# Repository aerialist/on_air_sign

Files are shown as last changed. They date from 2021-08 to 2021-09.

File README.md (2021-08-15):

# on_air_sign
An ON_AIR sign board with RGB LED matrix and a separate controller 

# make secret.py file
You would need to make secret.py file with following contents:

secrets = {
    'ssid' : 'yourssid', # home wifi access point ssid
    'password' : 'ssidpassword', # password for ssid
    'timezone' : "Asia/Tokyo", # http://worldtimeapi.org/timezones
    'aio_username': "aiouser", # Adafruit IO user name
    'aio_password': "aiokey", # Adafruit IO password
    'broker': "awsiotxxx.amazonaws.com", # AWS IoT Device data endpoint
    "client_id": "on_air_sign_featherm4", # AWS IoT Things name for testing
    "client_id_controller": "on_air_sign_controller", # AWS IoT Things name for controller
    "client_id_matrix": "on_air_sign_matrix", # AWS IoT Things name for matrix
}

# copy AWS IoT device certificates and private keys

Define AWS IoT Thing for controller and matrix. Download device certificates and private keys in aws folder.

aws/aws_cert_controller.pem.crt
aws/aws_cert_matrix.pem.crt
aws/private_controller.pem.key
aws/private_matrix.pem.key

# code to use Adafruit IO

code_controller.py
code_matrix.py

Copy them as code.py to controller and matrix.

# code to use AWS IoT

code_controller_aws.py
code_matrix_aws.py

Copy them as code.py to controller and matrix.

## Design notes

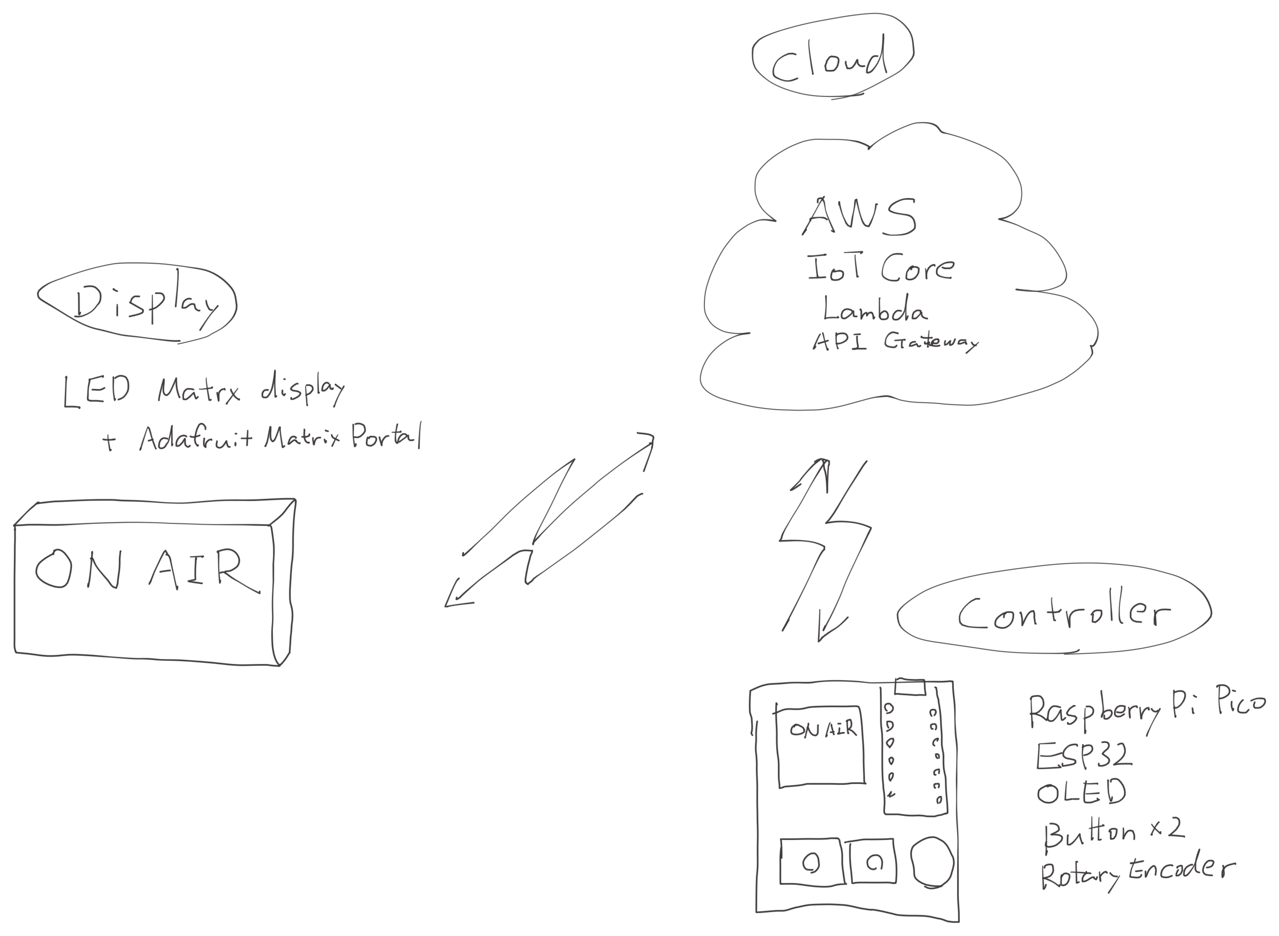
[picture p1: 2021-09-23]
images/onairsign_diagram.png

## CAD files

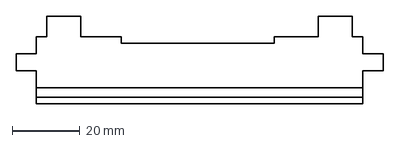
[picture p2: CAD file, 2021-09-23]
Mech/Body11.dxf
108.0 x 25.8 mm

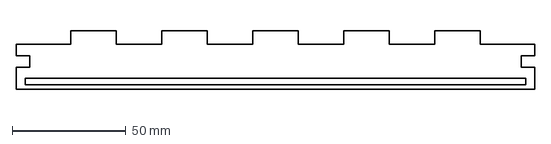
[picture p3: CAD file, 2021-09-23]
Mech/Body4.dxf
228.0 x 25.8 mm

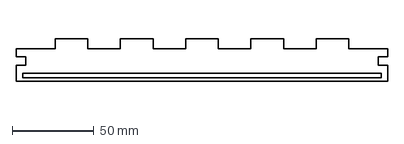
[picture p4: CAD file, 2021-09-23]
Mech/Body5.dxf
228.0 x 25.8 mm

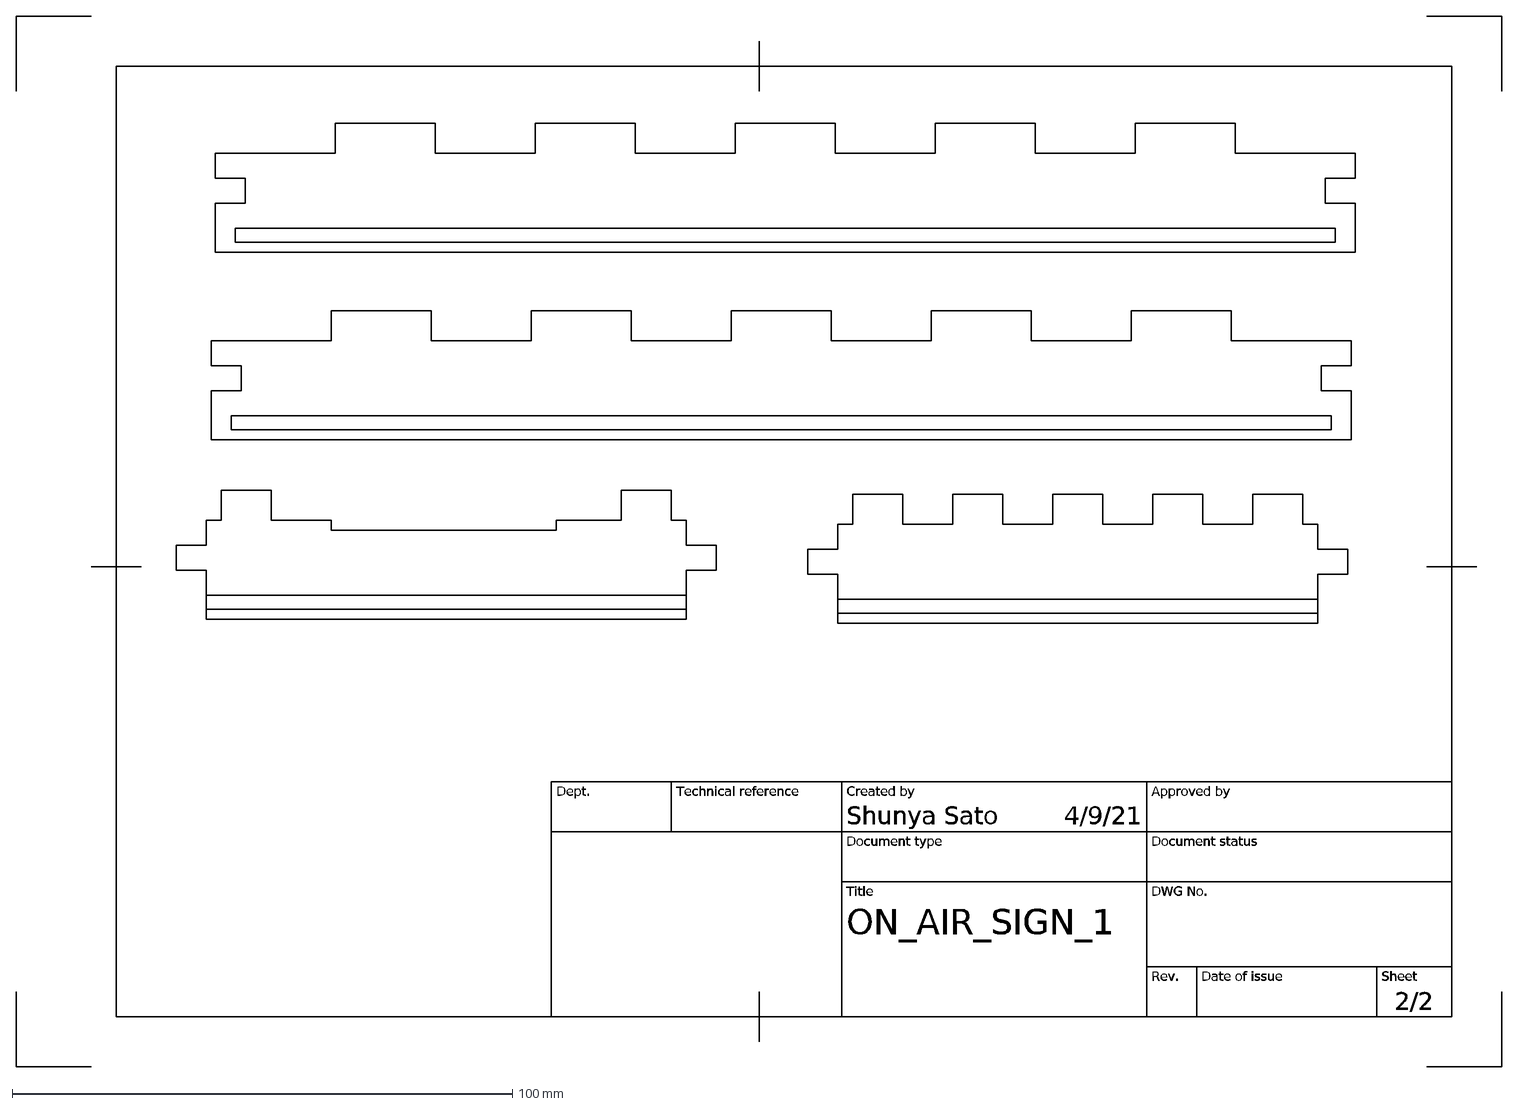
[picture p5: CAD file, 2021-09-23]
Mech/ON_AIR_SIGN_1 Drawing v3 Sheet2.dxf
4/9/21
2/2
ON_AIR_SIGN_1
Shunya Sato
Dept.
Technical reference
Created by
Approved by
Document type
Document status
Title
DWG No.
Rev.
Date of issue
Sheet

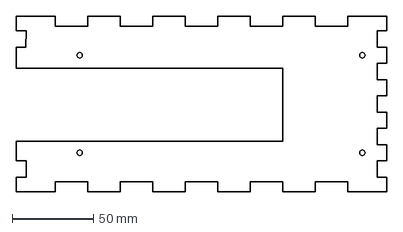
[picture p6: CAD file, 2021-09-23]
Mech/BackLid.dxf
228.0 x 108.0 mm

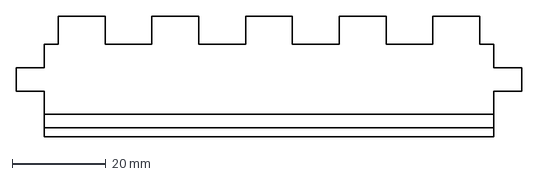
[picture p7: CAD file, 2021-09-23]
Mech/Body6.dxf
108.0 x 25.8 mm

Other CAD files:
Mech/ON_AIR_SIGN_1 Drawing v3.dwg

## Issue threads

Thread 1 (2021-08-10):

Move ESP_RESET to Pico GP16

aerialist, 2021-08-10:
ESP_RESET and ESP_GPIO0 (and ESP_CS) are used by pass through firmware.

https://learn.adafruit.com/quickstart-raspberry-pi-rp2040-with-ble-and-circuitpython/assembly

https://github.com/adafruit/Adafruit_Learning_System_Guides/blob/main/Adafruit_ESP32_Arduino_Demos/SerialESPPassthrough/serial_passthru_rp2040/serial_passthrough.c

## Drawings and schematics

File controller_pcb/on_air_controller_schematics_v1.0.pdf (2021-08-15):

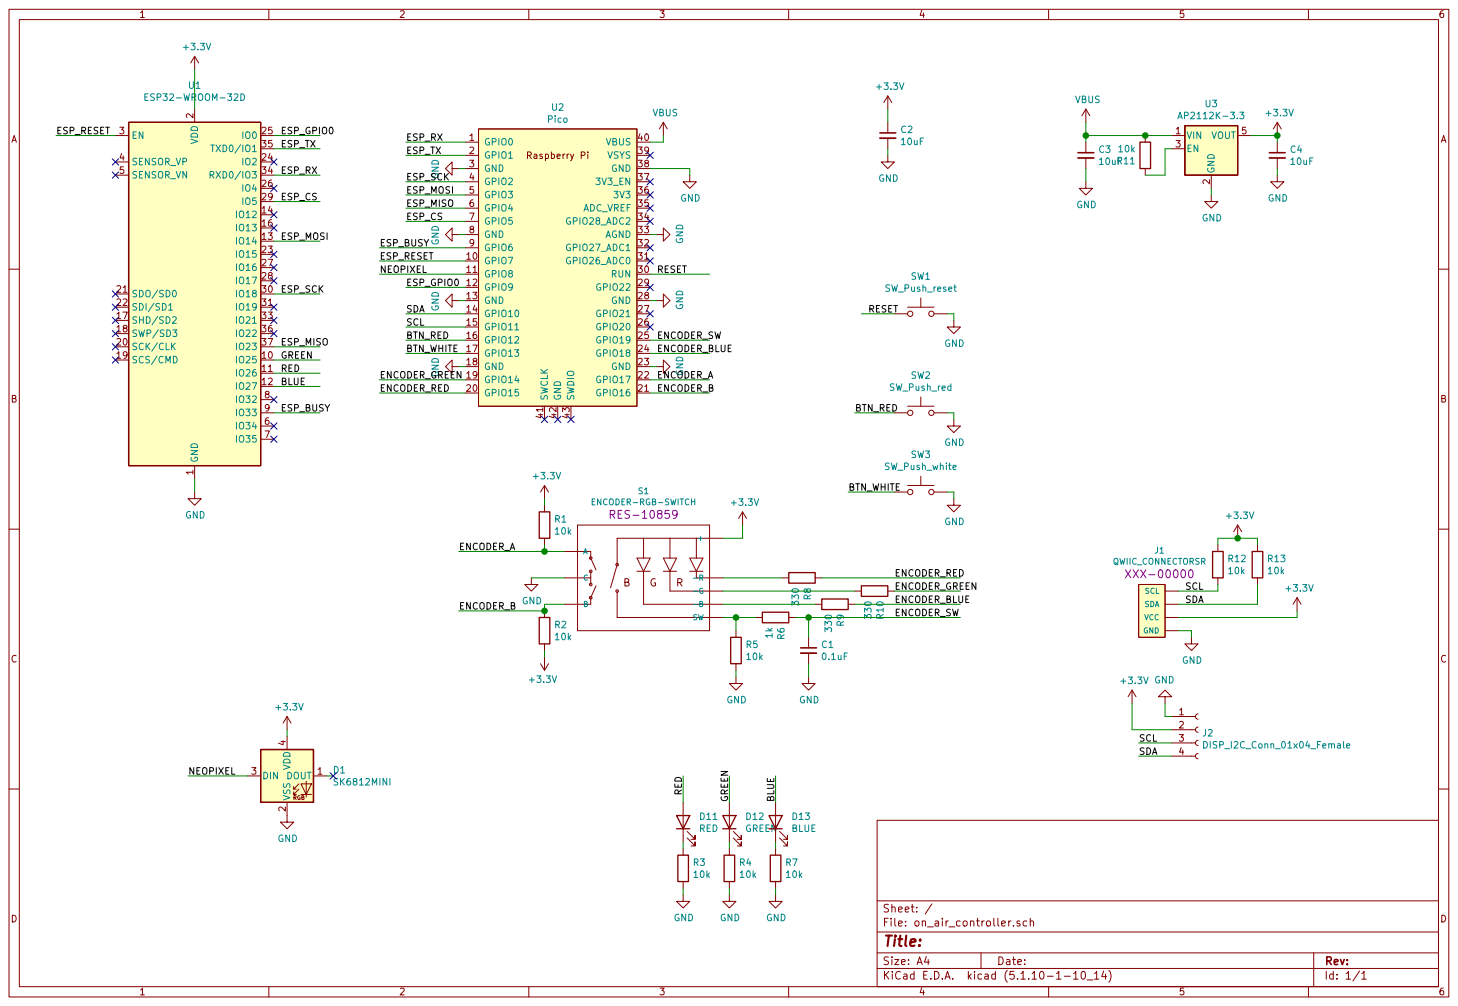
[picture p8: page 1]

2 SCK/CLK 20 SDO/SD0 21 SDI/SD1 22

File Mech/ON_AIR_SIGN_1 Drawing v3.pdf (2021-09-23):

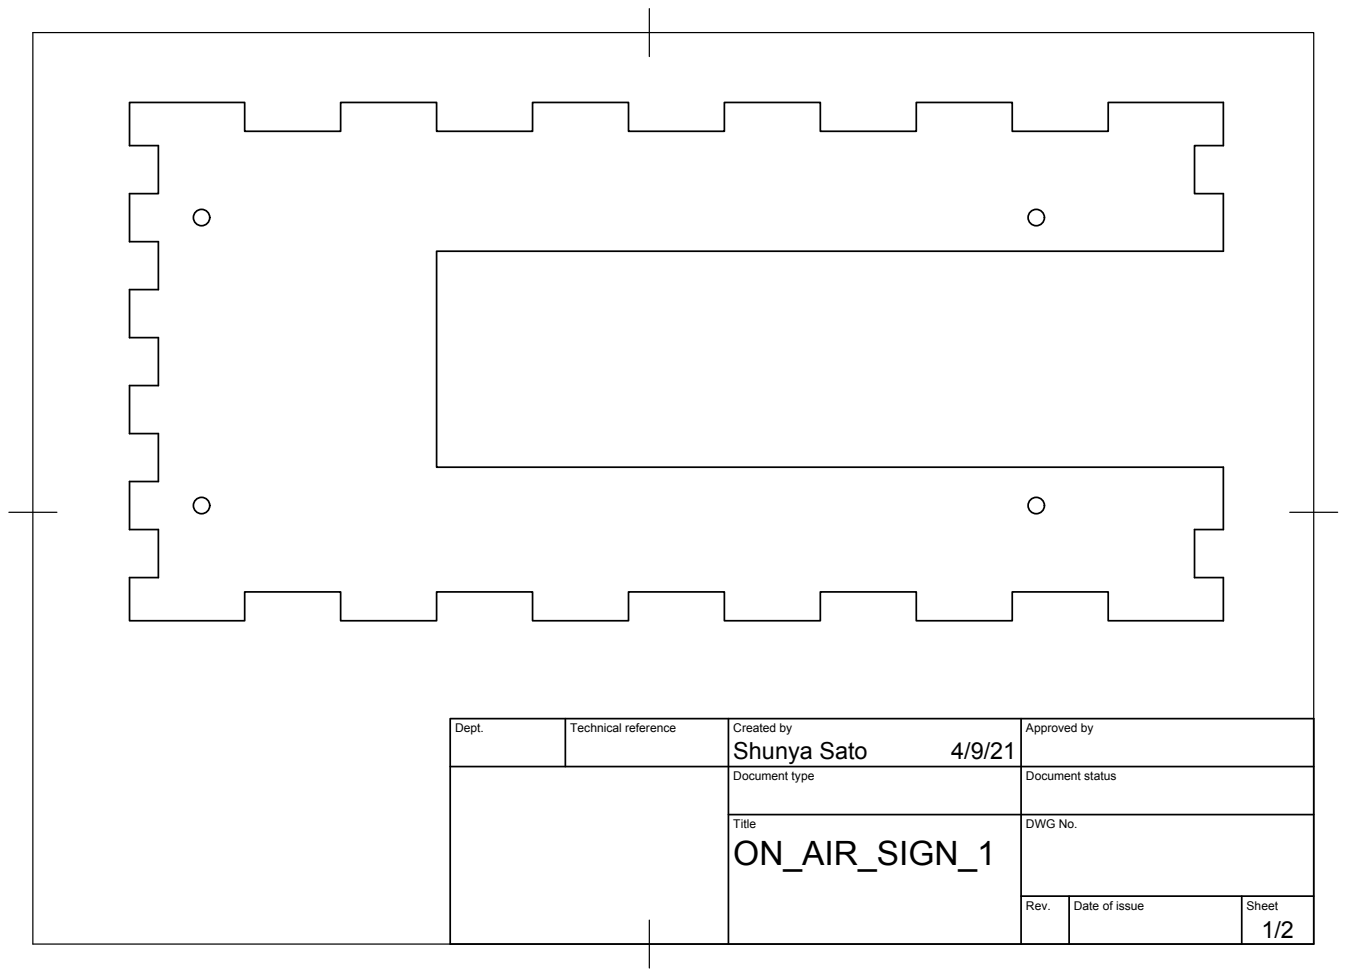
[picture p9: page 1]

Dept. | Technical reference | Created by Shunya Sato 4/9/21 | Approved by

Document type | Document status

Title ON_AIR_SIGN_1 | DWG No.

Rev. | Date of issue | Sheet 1/2

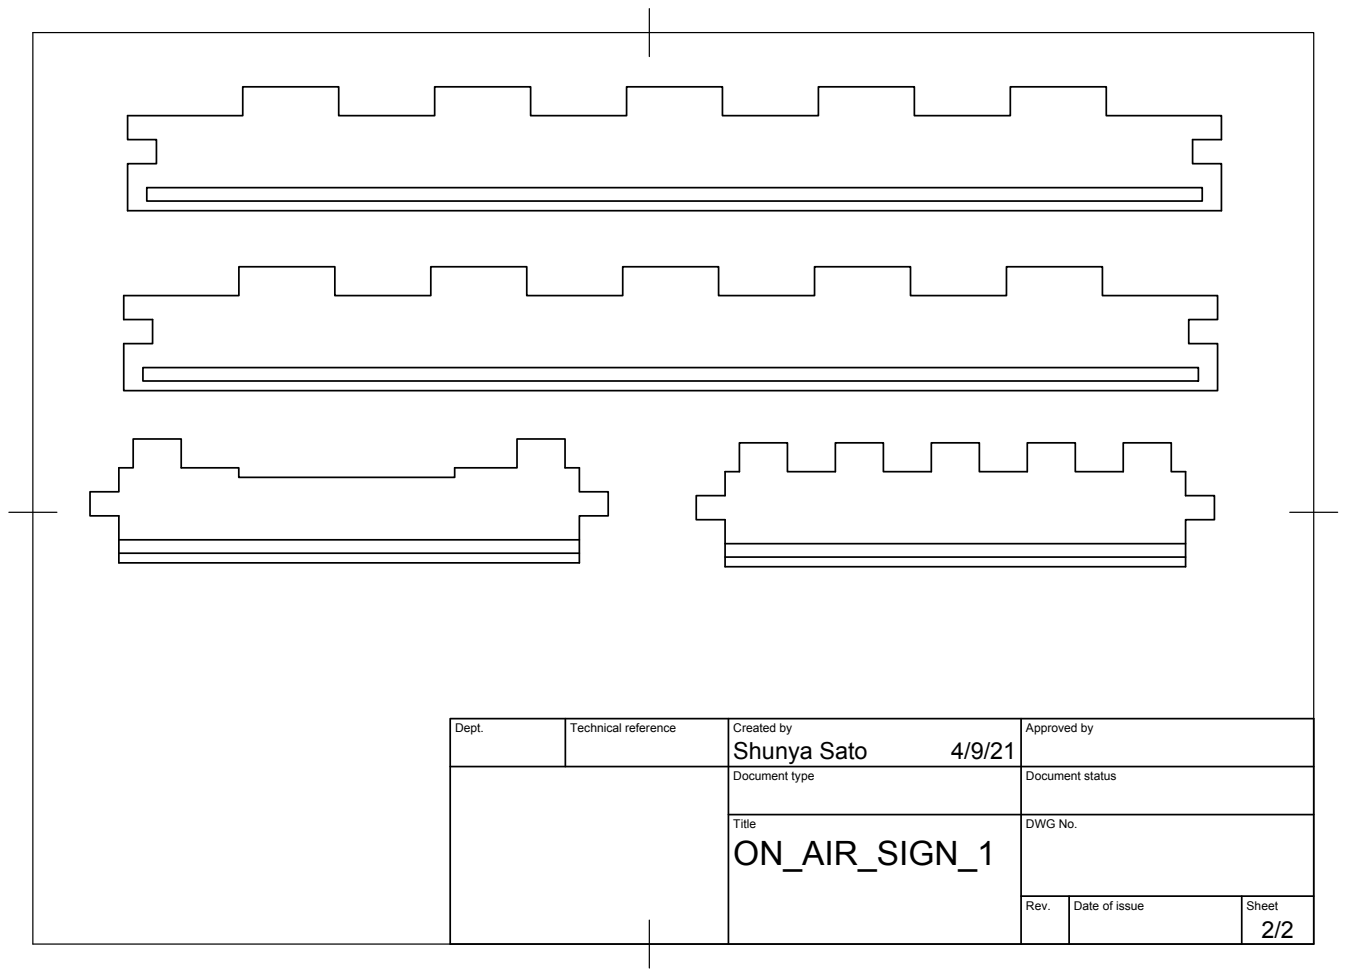
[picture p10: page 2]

Dept. | Technical reference | Created by Shunya Sato 4/9/21 | Approved by

Document type | Document status

Title ON_AIR_SIGN_1 | DWG No.

Rev. | Date of issue | Sheet 2/2

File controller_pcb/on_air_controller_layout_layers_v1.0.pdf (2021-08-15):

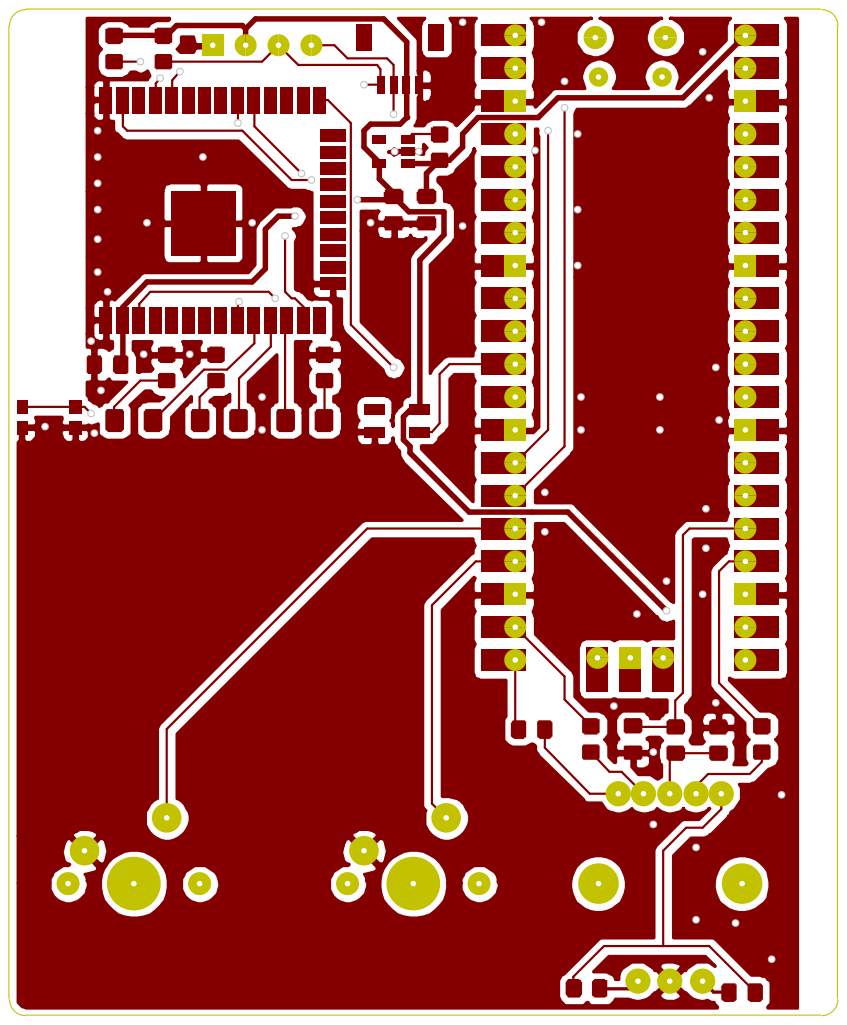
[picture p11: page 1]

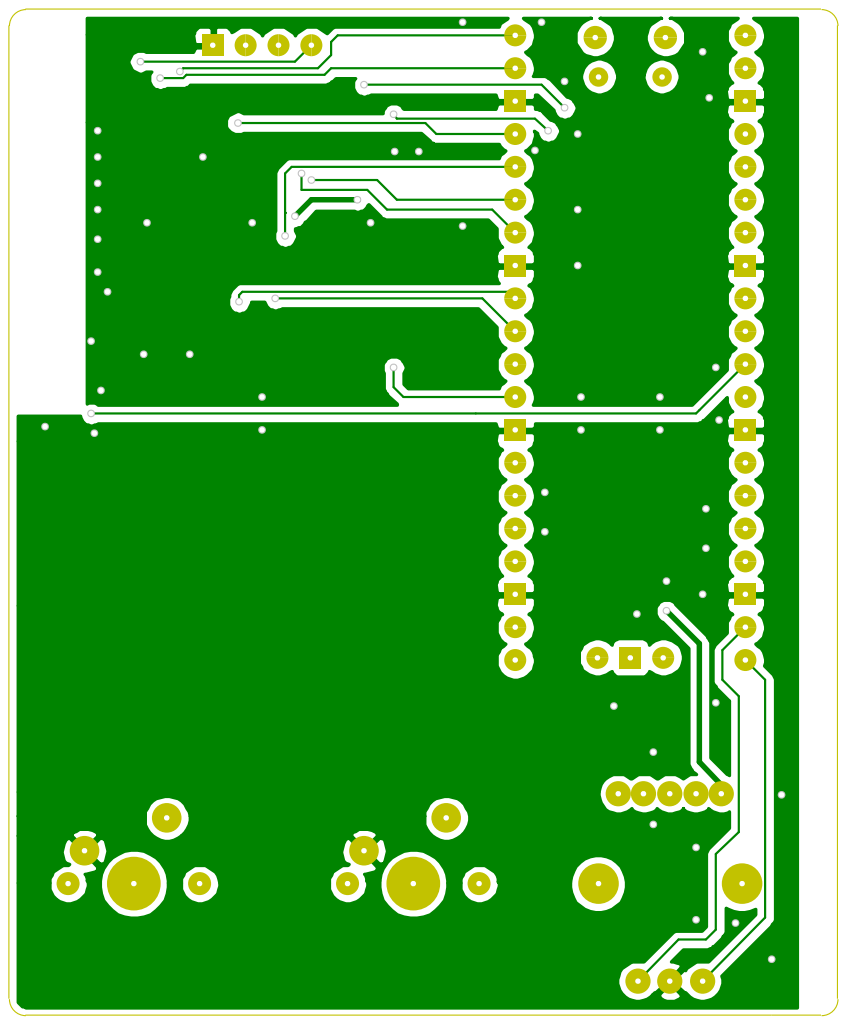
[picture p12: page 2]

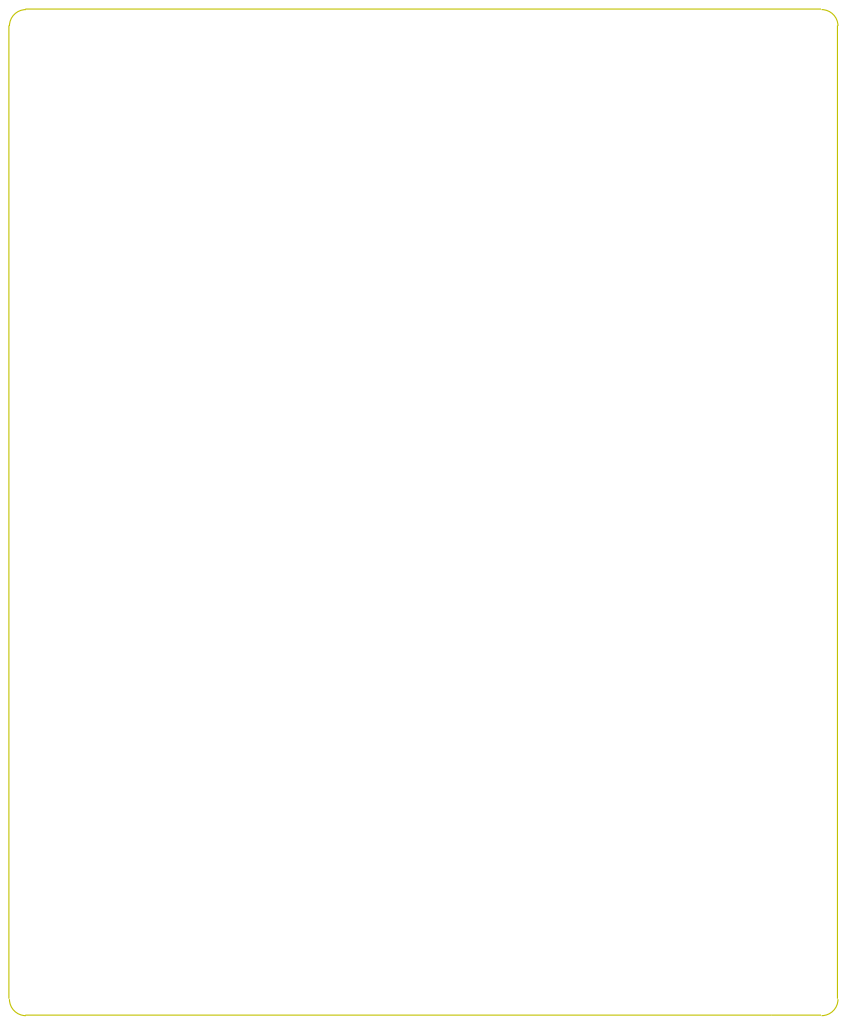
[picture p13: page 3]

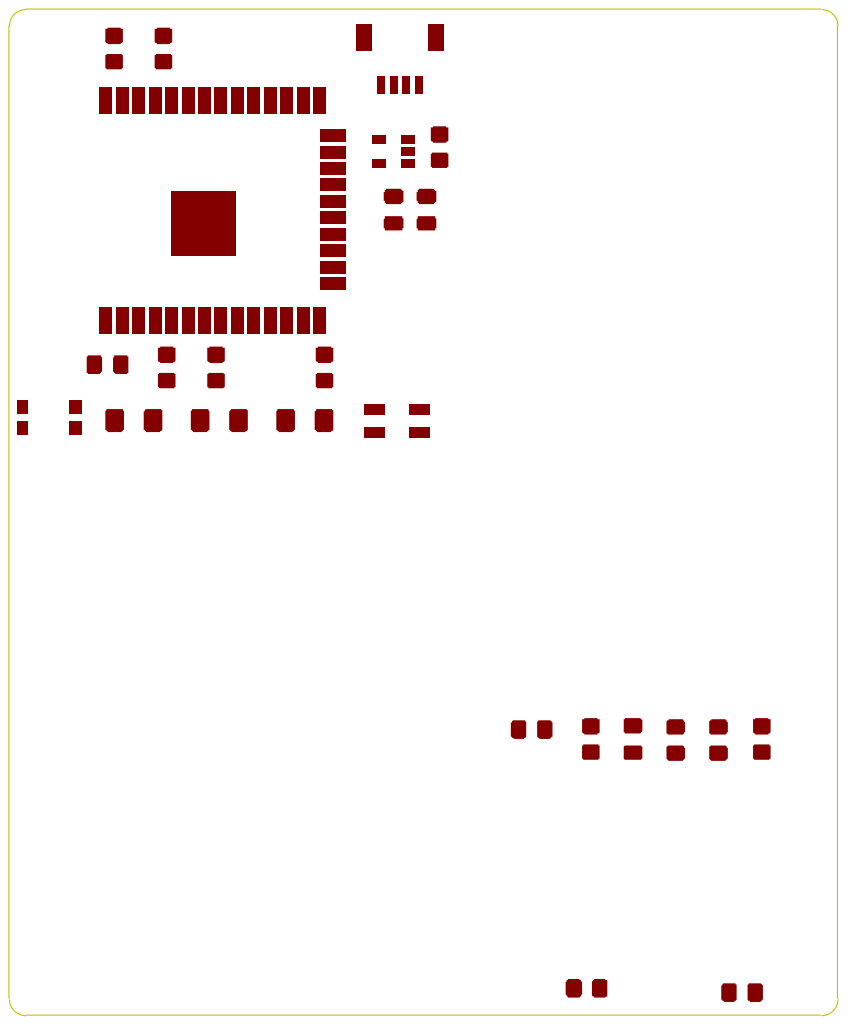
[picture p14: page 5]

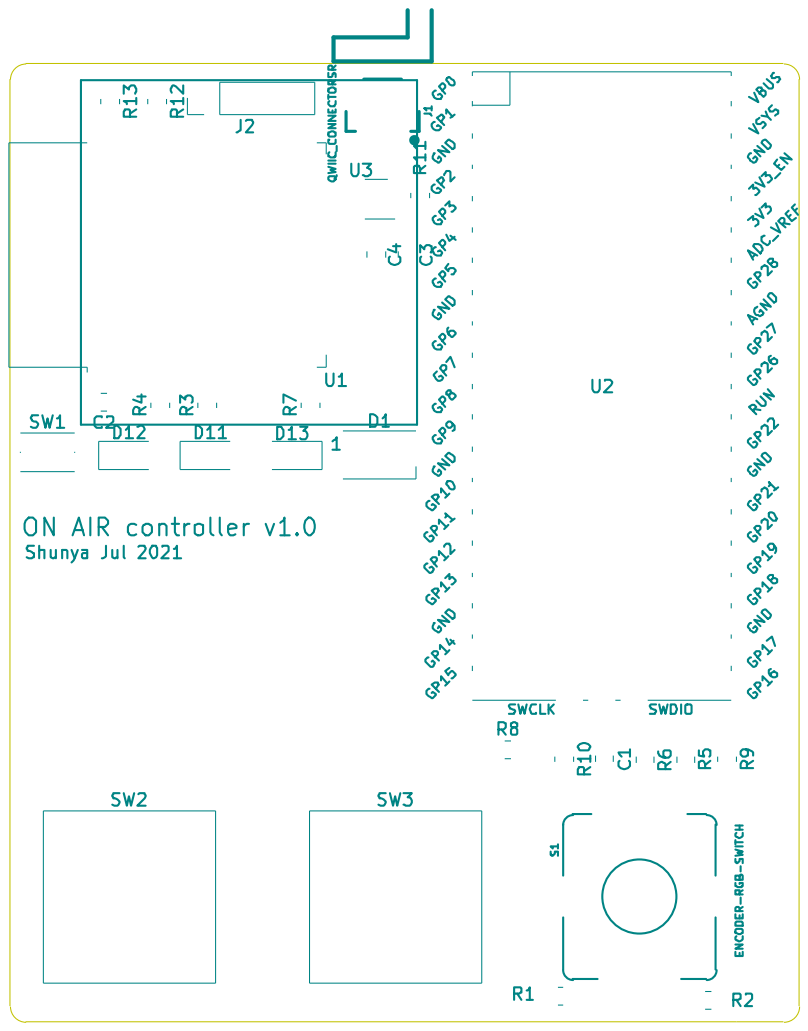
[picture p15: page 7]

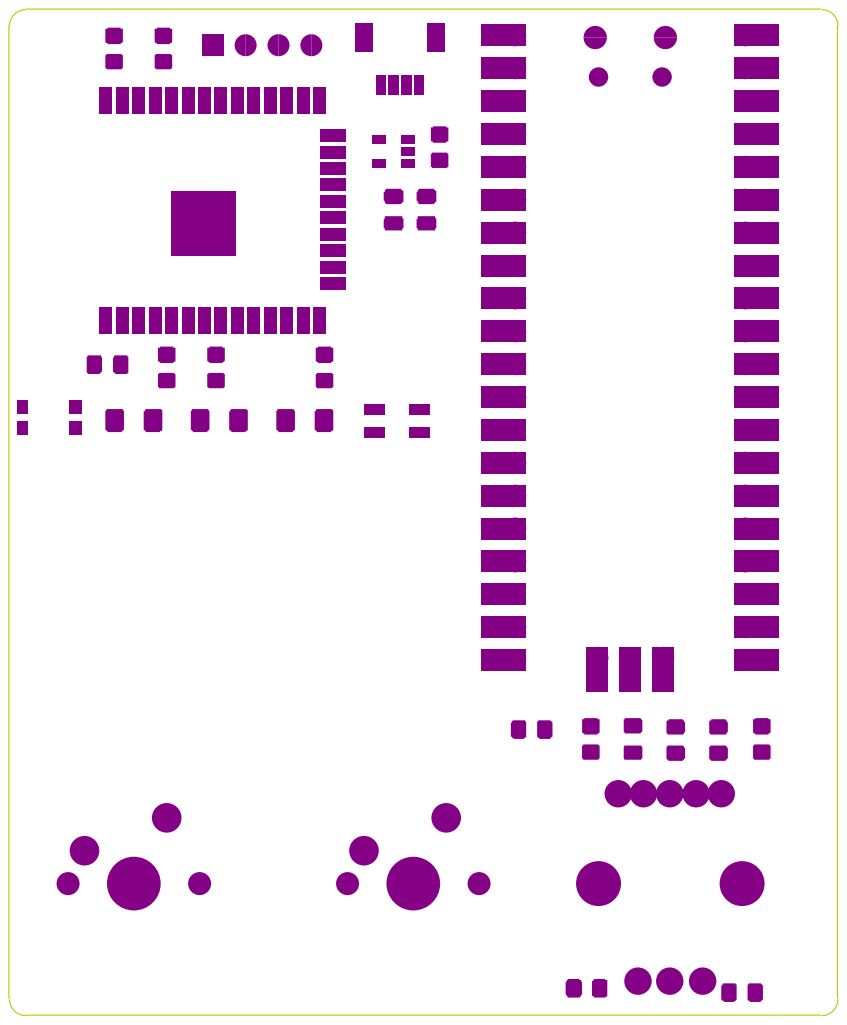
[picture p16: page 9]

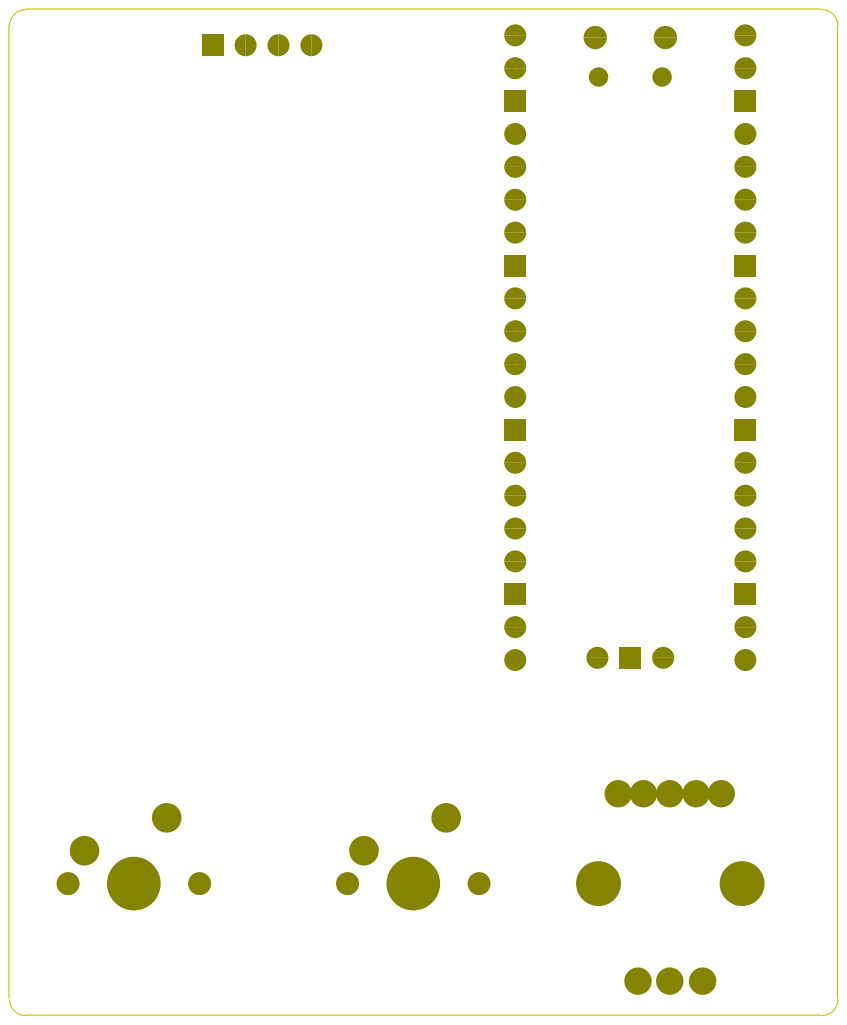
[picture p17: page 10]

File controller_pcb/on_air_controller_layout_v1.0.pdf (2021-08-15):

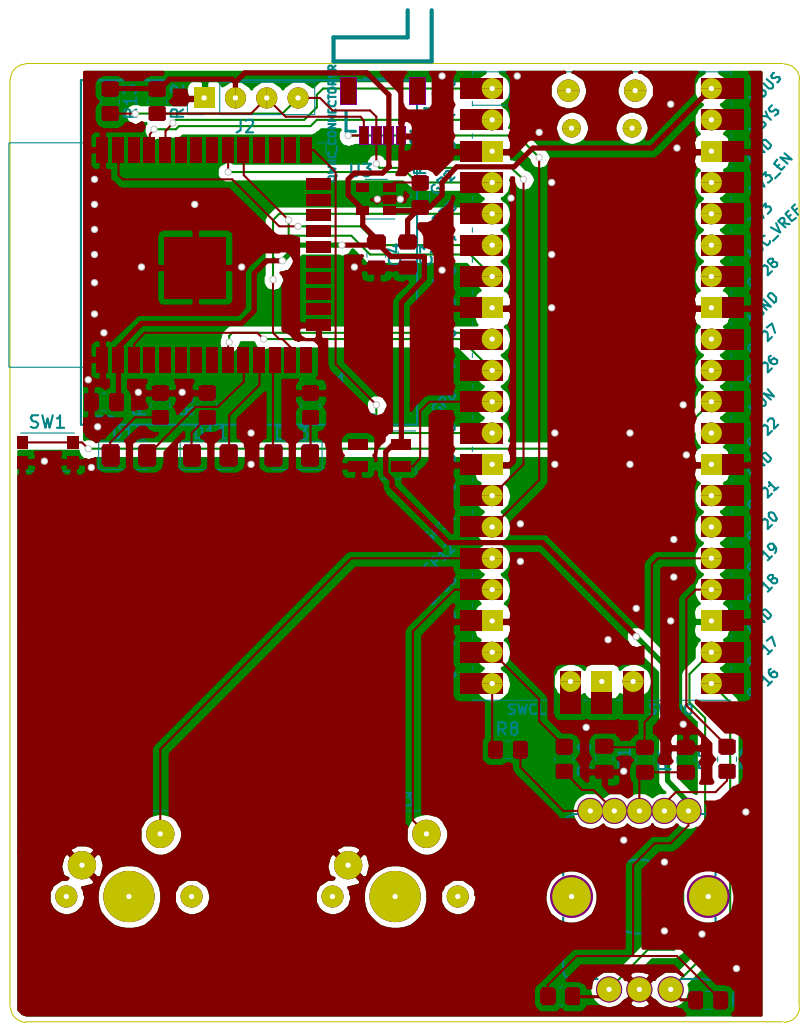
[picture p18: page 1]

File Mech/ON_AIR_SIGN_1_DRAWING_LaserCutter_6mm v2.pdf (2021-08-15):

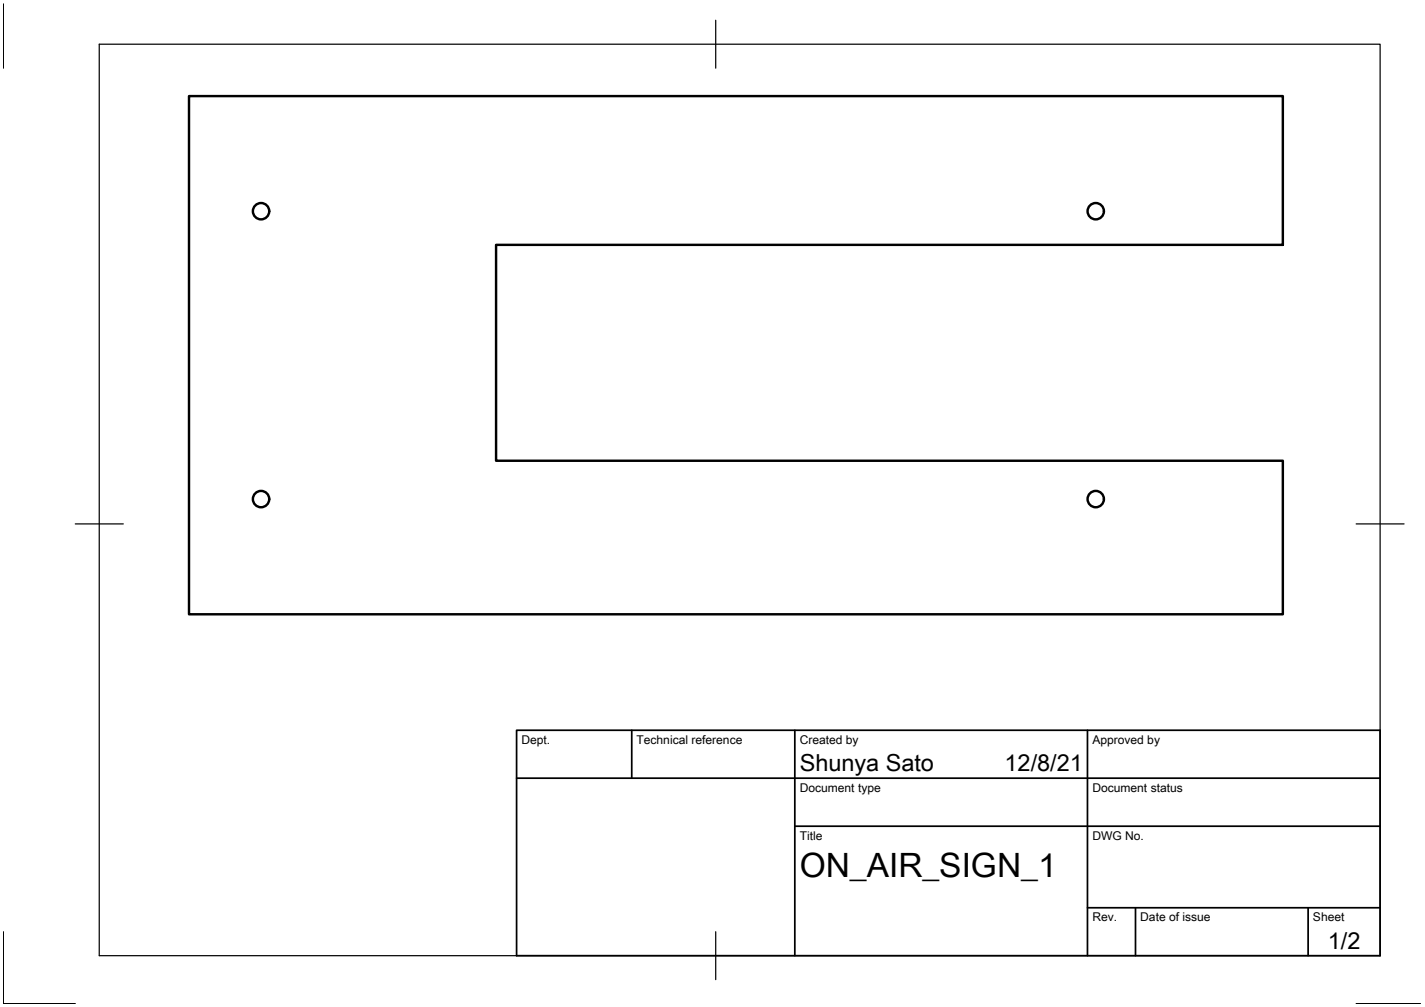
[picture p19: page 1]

Dept. | Technical reference | Created by Shunya Sato 12/8/21 | Approved by

Document type | Document status

Title ON_AIR_SIGN_1 | DWG No.

Rev. | Date of issue | Sheet 1/2


Dept. | Technical reference | Created by Shunya Sato 12/8/21 | Approved by

Document type | Document status

Title ON_AIR_SIGN_1 | DWG No.

Rev. | Date of issue | Sheet 2/2

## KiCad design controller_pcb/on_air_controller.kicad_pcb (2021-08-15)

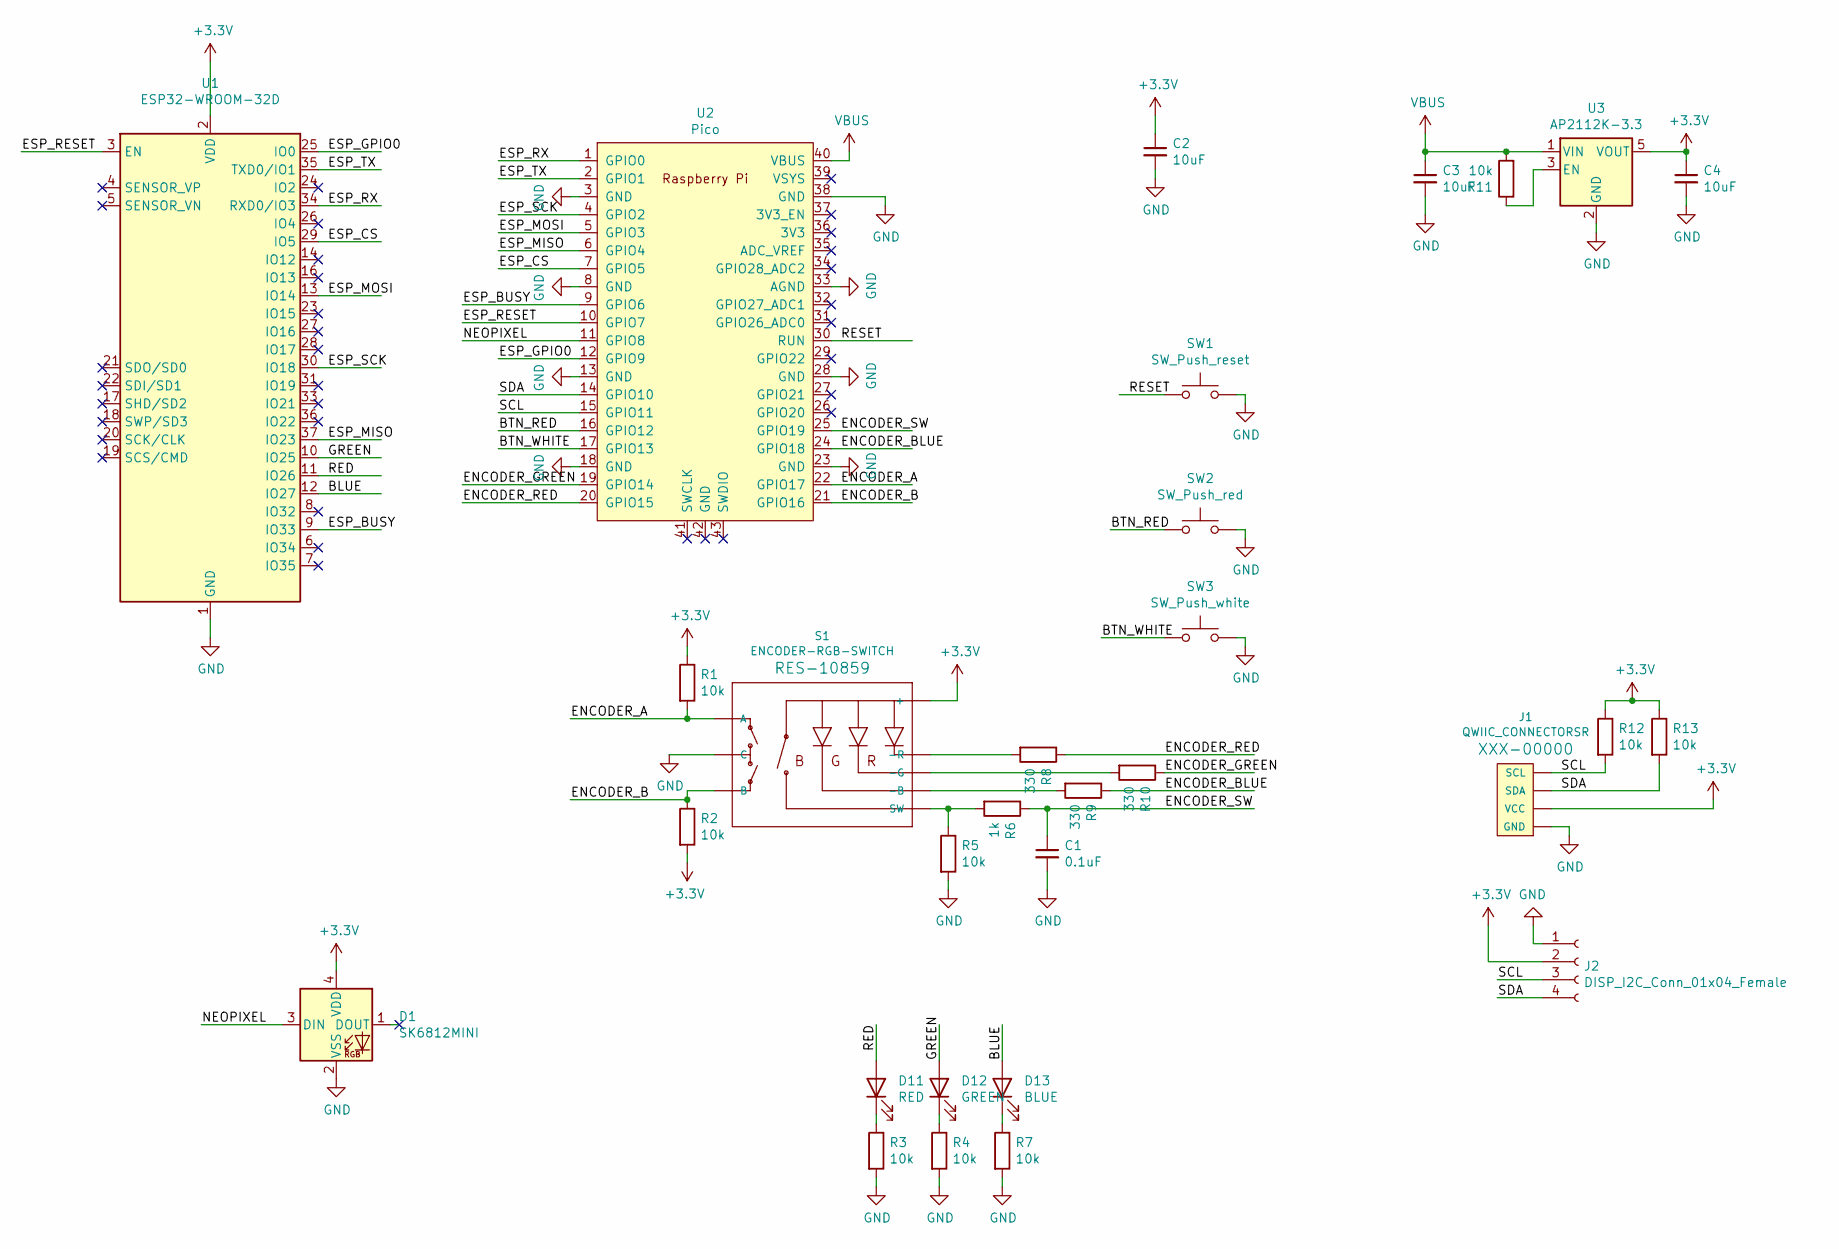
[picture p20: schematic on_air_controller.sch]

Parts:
C1: 0.1uF; C_0805_2012Metric_Pad1.18x1.45mm_HandSolder
C2, C3, C4: 10uF; C_0805_2012Metric_Pad1.18x1.45mm_HandSolder
D1: SK6812MINI; LED_SK6812MINI_PLCC4_3.5x3.5mm_P1.75mm
D11: RED; LED_1206_3216Metric_Pad1.42x1.75mm_HandSolder
D12: GREEN; LED_1206_3216Metric_Pad1.42x1.75mm_HandSolder
D13: BLUE; LED_1206_3216Metric_Pad1.42x1.75mm_HandSolder
J1: QWIIC_CONNECTORSR; 1X04_1MM_RA_STRESSRELIEF
J2: DISP_I2C_Conn_01x04_Female; OLED_0.96inch_PinHeader_1x04_P2.54mm_Vertical
R1, R2, R3, R4, R5, R7, R11, R12, R13: 10k; R_0805_2012Metric_Pad1.20x1.40mm_HandSolder
R6: 1k; R_0805_2012Metric_Pad1.20x1.40mm_HandSolder
R8, R9, R10: 330; R_0805_2012Metric_Pad1.20x1.40mm_HandSolder
S1: ENCODER-RGB-SWITCH; ENCODER_LED_3
SW1: SW_Push_reset; SW_Push_1P1T_NO_CK_KMR2
SW2: SW_Push_red; SW_Cherry_MX_1.00u_PCB
SW3: SW_Push_white; SW_Cherry_MX_1.00u_PCB
U1: ESP32-WROOM-32D; ESP32-WROOM-32
U2: Pico; RPi_Pico_SMD_TH
U3: AP2112K-3.3; SOT-23-5

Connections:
+3V3: C2.1, C4.1, D1.4 (VDD), J1.2 (VCC), J2.2, R1.1, R2.2, R12.1, R13.1, S1.5 (+), U1.2 (VDD), U3.5 (VOUT)
/BLUE: D13.2 (A), U1.12 (IO27)
/BTN_RED: SW2.1, U2.16 (GPIO12)
/BTN_WHITE: SW3.1, U2.17 (GPIO13)
/ENCODER_A: R1.2, S1.A, U2.22 (GPIO17)
/ENCODER_B: R2.1, S1.B, U2.21 (GPIO16)
/ENCODER_BLUE: R9.1, U2.24 (GPIO18)
/ENCODER_GREEN: R10.1, U2.19 (GPIO14)
/ENCODER_RED: R8.1, U2.20 (GPIO15)
/ENCODER_SW: C1.1, R6.1, U2.25 (GPIO19)
/ESP_BUSY: U1.9 (IO33), U2.9 (GPIO6)
/ESP_CS: U1.29 (IO5), U2.7 (GPIO5)
/ESP_GPIO0: U1.25 (IO0), U2.12 (GPIO9)
/ESP_MISO: U1.37 (IO23), U2.6 (GPIO4)
/ESP_MOSI: U1.13 (IO14), U2.5 (GPIO3)
/ESP_RESET: U1.3 (EN), U2.10 (GPIO7)
/ESP_RX: U1.34 (RXD0/IO3), U2.1 (GPIO0)
/ESP_SCK: U1.30 (IO18), U2.4 (GPIO2)
/ESP_TX: U1.35 (TXD0/IO1), U2.2 (GPIO1)
/GREEN: D12.2 (A), U1.10 (IO25)
/NEOPIXEL: D1.3 (DIN), U2.11 (GPIO8)
/RED: D11.2 (A), U1.11 (IO26)
/RESET: SW1.1, U2.30 (RUN)
/SCL: J1.4 (SCL), J2.3, R12.2, U2.15 (GPIO11)
/SDA: J1.3 (SDA), J2.4, R13.2, U2.14 (GPIO10)
GND: C1.2, C2.2, C3.2, C4.2, D1.2 (VSS), J1.1 (GND), J2.1, R3.2, R4.2, R5.2, R7.2, S1.C, SW1.2, SW2.2, SW3.2, U1.1 (GND), U1.15 (GND), U1.38 (GND), U1.39 (GND), U2.3 (GND), U2.8 (GND), U2.13 (GND), U2.18 (GND), U2.23 (GND), U2.28 (GND), U2.33 (AGND), U2.38 (GND), U3.2 (GND)
unnamed: D11.1 (K), R3.1
unnamed: D12.1 (K), R4.1
unnamed: D13.1 (K), R7.1
unnamed: R5.1, R6.2, S1.3 (SW)
unnamed: R8.2, S1.1 (-R)
unnamed: R9.2, S1.4 (-B)
unnamed: R10.2, S1.2 (-G)
unnamed: R11.1, U3.3 (EN)
VBUS: C3.1, R11.2, U2.40 (VBUS), U3.1 (VIN)

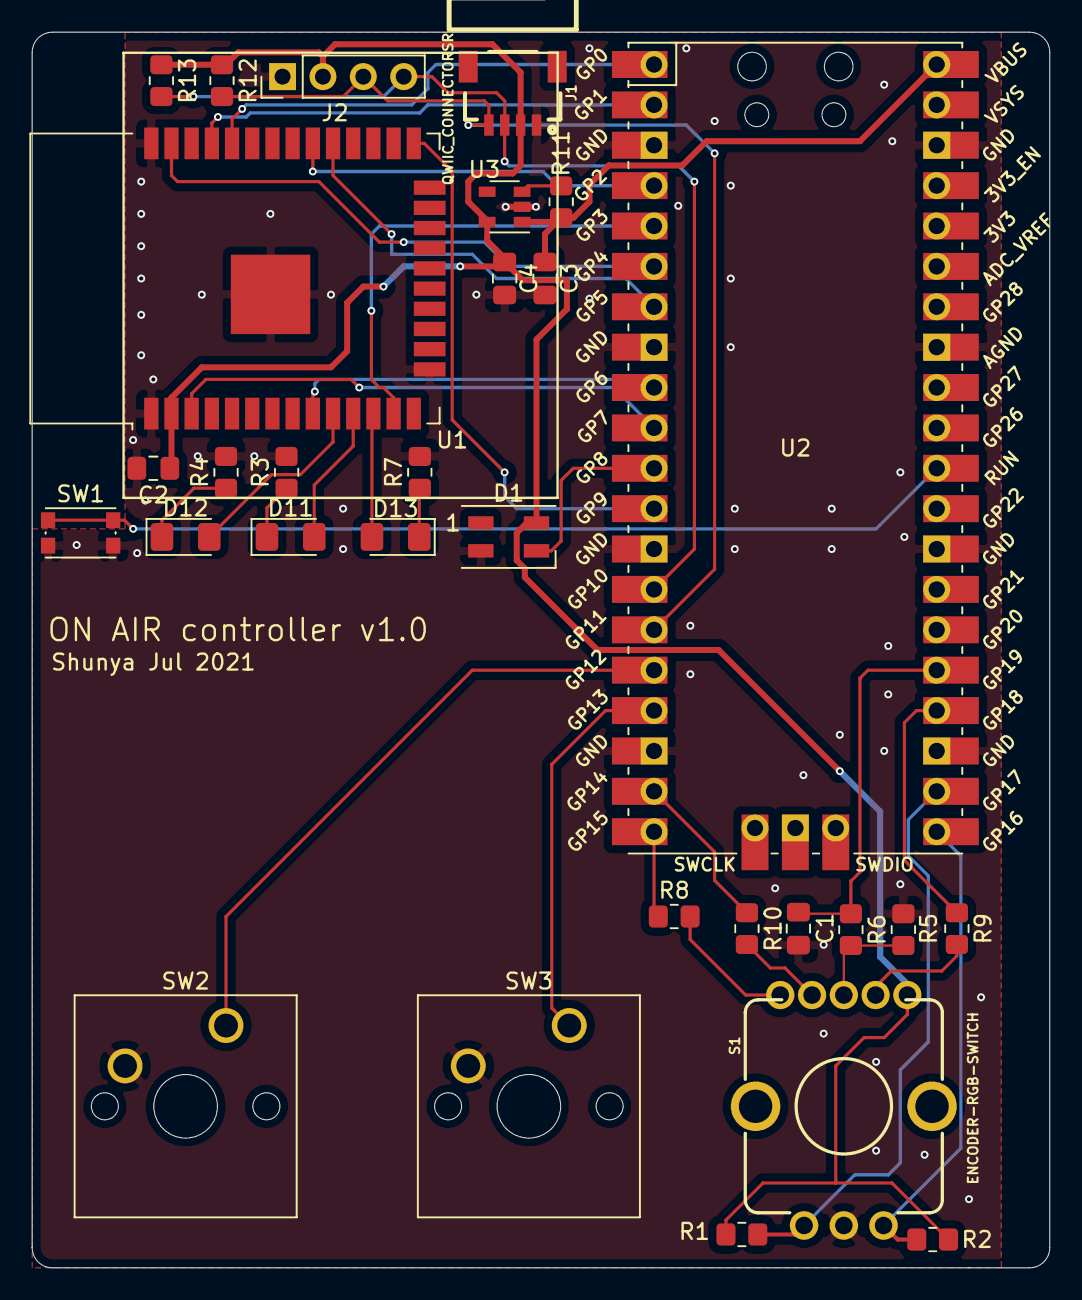
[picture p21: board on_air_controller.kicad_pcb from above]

Board: 2 copper layers, 64.0 x 77.7 mm, 30 parts (0 on the bottom side), 35 nets.

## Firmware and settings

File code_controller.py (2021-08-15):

def reference():
    pass
    # Raspberry Pi Pico RP2040
    #dir(board)
    #['__class__', 'A0', 'A1', 'A2', 'A3', 'GP0', 'GP1', 'GP10', 'GP11', 'GP12', 'GP13',
    #'GP14', 'GP15', 'GP16', 'GP17', 'GP18', 'GP19', 'GP2', 'GP20', 'GP21', 'GP22', 'GP23',
    #'GP24', 'GP25', 'GP26', 'GP26_A0', 'GP27', 'GP27_A1', 'GP28', 'GP28_A2', 'GP3', 'GP4',
    #'GP5', 'GP6', 'GP7', 'GP8', 'GP9', 'LED', 'SMPS_MODE', 'VBUS_SENSE', 'VOLTAGE_MONITOR']

    # ON_AIR_controller v1.0
    # GP12: red button
    # GP13: white button
    # GP17: Rotary Encoder A
    # GP16: Rotary Encoder B
    # GP15: Rotary Encoder LED Red
    # GP14: Rotary Encoder LED Green
    # GP18: Rotary Encoder LED Blue
    # GP19: Rotary Encoder Switch
    # GP2: AirLift SCK
    # GP3: AIrLift MOSI
    # GP4: AirLift MISO
    # GP5: AirLift CS
    # GP6: AirLift BUSY
    # GP7: AirLift !RST
    # GP8: neopixel
    # GP10: SDA
    # GP11: SCL
    # I2C SSD1306 OLED 128x64 display address 0x3c

    #>>> help("modules")
    #__main__          board             microcontroller   storage
    #_bleio            builtins          micropython       struct
    #_eve              busio             msgpack           supervisor
    #_pixelbuf         collections       neopixel_write    sys
    #adafruit_bus_device                 countio           os                terminalio
    #analogio          digitalio         pulseio           time
    #array             displayio         pwmio             touchio
    #audiobusio        errno             random            ulab
    #audiocore         fontio            re                usb_hid
    #audiomp3          framebufferio     rgbmatrix         usb_midi
    #audiopwmio        gamepad           rotaryio          vectorio
    #binascii          gc                rp2pio            watchdog
    #bitbangio         io                rtc
    #bitmaptools       json              sdcardio
    #bitops            math              sharpdisplay
    #Plus any modules on the filesystem

import board
import time
import rtc
import digitalio
from digitalio import DigitalInOut
from adafruit_debouncer import Debouncer
import rotaryio
import busio
from adafruit_datetime import datetime, timedelta
import displayio
import adafruit_displayio_ssd1306
import terminalio
from adafruit_display_text.label import Label
from adafruit_display_shapes.rect import Rect
from adafruit_display_shapes.line import Line
import neopixel
from adafruit_esp32spi import adafruit_esp32spi
from adafruit_esp32spi import adafruit_esp32spi_wifimanager
import adafruit_esp32spi.adafruit_esp32spi_socket as socket
#import adafruit_requests as requests
import adafruit_minimqtt.adafruit_minimqtt as MQTT
from adafruit_io.adafruit_io import IO_MQTT

from secrets import secrets

# OLED Display
WIDTH = 128
HEIGHT = 64
BORDER = 5
BLACK = 0x000000
WHITE = 0xFFFFFF

FEED_ONAIR = "matrix-onair"
FEED_TEXT = "matrix-text"
tz_offset=9 * 60 * 60 # Time zone offset from UTC in seconds

print("ONAIR display controller")

led = digitalio.DigitalInOut(board.LED)
led.direction = digitalio.Direction.OUTPUT

# Rotary Encoder
encoder = rotaryio.IncrementalEncoder(board.GP16, board.GP17)
led_red = digitalio.DigitalInOut(board.GP15)
led_red.direction = digitalio.Direction.OUTPUT
led_red.value = True # OFF
led_green = digitalio.DigitalInOut(board.GP14)
led_green.direction = digitalio.Direction.OUTPUT
led_green.value = True # OFF
led_blue = digitalio.DigitalInOut(board.GP18)
led_blue.direction = digitalio.Direction.OUTPUT
led_blue.value = True # OFF
btnRotaryPin = digitalio.DigitalInOut(board.GP19)
btnRotaryPin.direction = digitalio.Direction.INPUT
btnRotaryPin.pull = digitalio.Pull.UP
#btnRotary = Debouncer(btnRotaryPin, interval=0.1)
btnRotary = Debouncer(btnRotaryPin)

btnRedPin = digitalio.DigitalInOut(board.GP12)
btnRedPin.direction = digitalio.Direction.INPUT
btnRedPin.pull = digitalio.Pull.UP
btnRed = Debouncer(btnRedPin)

btnWhitePin = digitalio.DigitalInOut(board.GP13)
btnWhitePin.direction = digitalio.Direction.INPUT
btnWhitePin.pull = digitalio.Pull.UP
btnWhite = Debouncer(btnWhitePin)

displayio.release_displays()
i2c = busio.I2C(board.GP11, board.GP10)
display_bus = displayio.I2CDisplay(i2c, device_address=0x3c)
display = adafruit_displayio_ssd1306.SSD1306(display_bus, width=WIDTH, height=HEIGHT)

splash = displayio.Group(max_size=10)

group_on = displayio.Group()
splash.append(group_on)
group_on.hidden = True
group_off = displayio.Group()
splash.append(group_off)
group_status = displayio.Group()
group_status.x = WIDTH-6
group_status.y = HEIGHT-2
splash.append(group_status)

rect_on = Rect(0, 0, WIDTH, HEIGHT//2, fill=WHITE)
group_on.append(rect_on)

label_onair = Label(terminalio.FONT, text="ON AIR", color=BLACK)
label_onair.scale=2
label_onair.anchor_point = (0.5, 0.5)
label_onair.anchored_position = (WIDTH//2, HEIGHT//4)
group_on.append(label_onair)

rect_off = Rect(0, 0, WIDTH, HEIGHT//2, fill=BLACK)
group_off.append(rect_off)

label_off = Label(terminalio.FONT, text="GOOD", color=WHITE)
label_off.scale=2
label_off.anchor_point = (0.5, 0.5)
label_off.anchored_position = (WIDTH//2, HEIGHT//4)
group_off.append(label_off)

label_time = Label(terminalio.FONT, text="13:30", color=WHITE)
label_time.scale=2
label_time.anchor_point = (0.5, 0.5)
label_time.anchored_position = (WIDTH//4, 3*(HEIGHT//4))
splash.append(label_time)
label_time.text = ""

line_time = Line(2,HEIGHT-2, WIDTH//2-2, HEIGHT-2, color=WHITE)
splash.append(line_time)

label_time_feed = Label(terminalio.FONT, text="13:30", color=WHITE)
label_time_feed.scale=2
label_time_feed.anchor_point = (0.5, 0.5)
label_time_feed.anchored_position = (3*WIDTH//4, 3*(HEIGHT//4))
splash.append(label_time_feed)
label_time_feed.text = ""

rect_status = Rect(0,0,5,5,fill=WHITE)
group_status.append(rect_status)

def turn_on():
    group_on.hidden = False
    group_off.hidden = True
    label_time.text = "13:30"

def turn_off():
    group_on.hidden = True
    group_off.hidden = False
    label_time.text = ""

display.show(splash)

esp32_cs = DigitalInOut(board.GP5)
esp32_ready = DigitalInOut(board.GP6)
esp32_reset = DigitalInOut(board.GP7)
spi = busio.SPI(board.GP2, board.GP3, board.GP4)
esp = adafruit_esp32spi.ESP_SPIcontrol(spi, esp32_cs, esp32_ready, esp32_reset)
# esp._debug = True
status_light = neopixel.NeoPixel(board.GP8, 1, brightness=0.2)
wifi = adafruit_esp32spi_wifimanager.ESPSPI_WiFiManager(esp, secrets, status_light)
#requests.set_socket(socket, esp)

def connected(client):
    # Connected function will be called when the client is connected to Adafruit IO.
    print("Connected to Adafruit IO! ")
    group_status.y -= 1

def subscribe(client, userdata, topic, granted_qos):
    # This method is called when the client subscribes to a new feed.
    print("Subscribed to {0} with QOS level {1}".format(topic, granted_qos))

def disconnected(client):
    # Disconnected function will be called when the client disconnects.
    print("Disconnected from Adafruit IO!")

def on_matrix_onair(client, topic, message):
    # Method called whenever user/feeds/led has a new value
    print("New message on topic {0}: {1} ".format(topic, message))
    if message == "ON":
        led.value = True
        group_on.hidden = False
        group_off.hidden = True
    elif message == "OFF":
        led.value = False
        group_on.hidden = True
        group_off.hidden = False
    else:
        print("Unexpected message on LED feed.")

def on_matrix_text(client, topic, message):
    print("New message on topic {0}: {1} ".format(topic, message))
    if message == ".":
        label_time_feed.text = ""
    else:
        label_time_feed.text = message

def update_time_area_text(position):
    dt = datetime.now() + timedelta(minutes=10*position) + timedelta(hours=1)
    pp = "{:02d}:{:02d}".format(dt.hour, dt.minute//10*10)
    #print(pp)
    label_time.text = pp

# Connect to WiFi
print("Connecting to WiFi...")
wifi.connect()
print("Connected!")
group_status.y -= 1

# Get time from NTP server and set system time
while True:
    # esp get_time fails in first few attemps
    try:
        now = esp.get_time()
    except ValueError as e:
        print(e)
        time.sleep(1)
    else:
        break
print(now)
now = time.localtime(now[0] + tz_offset)
print(now)
rtc.RTC().datetime = now
group_status.y -= 1

# Initialize MQTT interface with the esp interface
MQTT.set_socket(socket, esp)
mqtt_client = MQTT.MQTT(
    broker="io.adafruit.com",
    username=secrets["aio_username"],
    password=secrets["aio_password"],
)

io = IO_MQTT(mqtt_client)
io.on_connect = connected
io.on_disconnect = disconnected
io.on_subscribe = subscribe

io.add_feed_callback(FEED_ONAIR, on_matrix_onair)
io.add_feed_callback(FEED_TEXT, on_matrix_text)
print("Connecting to Adafruit IO...")
io.connect()
# Subscribe to all messages on the led feed
io.subscribe(FEED_ONAIR)
io.subscribe(FEED_TEXT)

def loop():
    last_position = None
    while True:
        #print(time.monotonic())
        btnRotary.update()
        btnRed.update()
        btnWhite.update()
        position = encoder.position
        if last_position is None or position != last_position:
            update_time_area_text(position)
        last_position = position
        if btnRed.rose == True:
            print("btnRed is pressed")
            led_blue.value = False
            led_green.value = True
            encoder.position = 0
            position = 0
            last_position = 0
            update_time_area_text(position)
            io.publish(FEED_ONAIR, "ON")
            print("Published!")
            io.publish(FEED_TEXT, ".")
            print("Published!")
        if btnWhite.rose == True:
            print("btnWhite is pressed")
            led_blue.value = True
            led_green.value = True
            io.publish(FEED_ONAIR, "OFF")
            print("Published!")
            io.publish(FEED_TEXT, ".")
            print("Published!")
        if btnRotary.rose == True:
            print("btnRotary is pressed")
            #if group_on.hidden == False:
            led_green.value = False
            io.publish(FEED_TEXT, "~"+label_time.text)
            print("Published!")
        # Poll for incoming messages
        try:
            io.loop(0.1)
        except (ValueError, RuntimeError, MQTT.MMQTTException) as e:
            print("Failed to get data, retrying\n", e)
            try:
                wifi.reset()
                wifi.connect()
                io.reconnect()
                #Failed to get data, retrying
                # ESP32 timed out on SPI select
                #Traceback (most recent call last):
                #  File "code.py", line 190, in <module>
                #  File "code.py", line 189, in <module>
                #  File "adafruit_io/adafruit_io.py", line 101, in reconnect
                #  File "adafruit_io/adafruit_io.py", line 101, in reconnect
                #AdafruitIO_MQTTError: MQTT Error: Unable to reconnect to Adafruit IO.
            except Exception as e:
                print("Still network error... keep trying.")
                print(e)
            continue

loop()

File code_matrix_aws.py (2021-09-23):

import time
import json
import board
import microcontroller
import busio
from digitalio import DigitalInOut
import displayio
import framebufferio
import rgbmatrix
import terminalio
from adafruit_bitmap_font import bitmap_font
from adafruit_display_text.label import Label
from adafruit_display_shapes.rect import Rect
import neopixel
from adafruit_esp32spi import adafruit_esp32spi
from adafruit_esp32spi import adafruit_esp32spi_wifimanager
import adafruit_esp32spi.adafruit_esp32spi_socket as socket
import adafruit_minimqtt.adafruit_minimqtt as MQTT
#from adafruit_io.adafruit_io import IO_MQTT
from adafruit_aws_iot import MQTT_CLIENT

from secrets import secrets

# Get device certificate
try:
    with open("aws/aws_cert_matrix.pem.crt", "rb") as f:
        DEVICE_CERT = f.read()
except ImportError:
    print("Certificate (aws_cert_matrix.pem.crt) not found on CIRCUITPY filesystem.")
    raise

# Get device private key
try:
    with open("aws/private_matrix.pem.key", "rb") as f:
        DEVICE_KEY = f.read()
except ImportError:
    print("Key (private_matrix.pem.key) not found on CIRCUITPY filesystem.")
    raise

# Matrix Display
WIDTH = 64
HEIGHT = 32
BLACK = 0x000000
WHITE = 0x505050
WHITE_DIM = 0x1a1a1a
RED = 0xFF0000
RED_DIM = 0x100000
GREEN_DIM = 0x001010
BLUE_DIM = 0x000010

shadow_topic = "$aws/things/{}/shadow".format(secrets["client_id_matrix"])

deco_font = bitmap_font.load_font("/fonts/Helvetica-Bold-16.bdf")

print("ONAIR display with MatrixPortal")

displayio.release_displays()
matrix = rgbmatrix.RGBMatrix(
    width=64, bit_depth=4,
    rgb_pins=[
        board.MTX_R1,
        board.MTX_G1,
        board.MTX_B1,
        board.MTX_R2,
        board.MTX_G2,
        board.MTX_B2
    ],
    addr_pins=[
        board.MTX_ADDRA,
        board.MTX_ADDRB,
        board.MTX_ADDRC,
        board.MTX_ADDRD
    ],
    clock_pin=board.MTX_CLK,
    latch_pin=board.MTX_LAT,
    output_enable_pin=board.MTX_OE
)
display = framebufferio.FramebufferDisplay(matrix)

splash = displayio.Group(max_size=10)

group_on = displayio.Group()
splash.append(group_on)
group_on.hidden = True
group_off = displayio.Group()
splash.append(group_off)

rect_on = Rect(0, 0, WIDTH, 2*HEIGHT//3, fill=RED_DIM, outline=WHITE)
group_on.append(rect_on)

label_onair = Label(deco_font, text="ON AIR", color=WHITE)
label_onair.scale=1
label_onair.anchor_point = (0.5, 0.5)
label_onair.anchored_position = (WIDTH//2, HEIGHT//4+2)
group_on.append(label_onair)

rect_off = Rect(0, 0, WIDTH, 2*HEIGHT//3, fill=BLACK)
group_off.append(rect_off)

label_off = Label(deco_font, text="GOOD", color=GREEN_DIM)
label_off.scale=1
label_off.anchor_point = (0.5, 0.5)
label_off.anchored_position = (WIDTH//2, HEIGHT//4+2)
group_off.append(label_off)

label_time = Label(terminalio.FONT, text="13:30", color=WHITE_DIM)
label_time.anchor_point = (0.5, 0.5)
label_time.anchored_position = (WIDTH//2, 3*(HEIGHT//4)+1)
splash.append(label_time)
label_time.text = ""

rect_status = Rect(63,31,1,1,fill=RED_DIM)
splash.append(rect_status)

def turn_on():
    group_on.hidden = False
    group_off.hidden = True
    label_time.text = "13:30"

def turn_off():
    group_on.hidden = True
    group_off.hidden = False
    label_time.text = ""

display.show(splash)

# If you are using a board with pre-defined ESP32 Pins:
esp32_cs = DigitalInOut(board.ESP_CS)
esp32_ready = DigitalInOut(board.ESP_BUSY)
esp32_reset = DigitalInOut(board.ESP_RESET)
spi = busio.SPI(board.SCK, board.MOSI, board.MISO)
esp = adafruit_esp32spi.ESP_SPIcontrol(spi, esp32_cs, esp32_ready, esp32_reset)
status_light = neopixel.NeoPixel(
    board.NEOPIXEL, 1, brightness=0.2
)
wifi = adafruit_esp32spi_wifimanager.ESPSPI_WiFiManager(esp, secrets, status_light)

# Set AWS Device Certificate
esp.set_certificate(DEVICE_CERT)

# Set AWS RSA Private Key
esp.set_private_key(DEVICE_KEY)

def connected(client, userdata, flags, rc):
    # Connected function will be called when the client is connected to Adafruit IO.
    print('Connected to AWS IoT!')
    print('Flags: {0}\nRC: {1}'.format(flags, rc))
    rect_status.fill = BLUE_DIM

    print("Subscribing to matrix shadow update delta...")
    #aws_iot.shadow_subscribe()
    aws_iot.subscribe(shadow_topic + "/update/delta")

    print("Subscribing to matrix shadow get...")
    #aws_iot.shadow_get_subscribe()  
    aws_iot.subscribe(shadow_topic + "/get/accepted")

    print("Publish matrix shadow get")
    #aws_iot.shadow_get()
    aws_iot.publish(shadow_topic + "/get", "{}")

def subscribed(client, userdata, topic, granted_qos):
    # This method is called when the client subscribes to a new feed.
    print("Subscribed to {0} with QOS level {1}".format(topic, granted_qos))
    rect_status.fill = WHITE_DIM

def unsubscribed(client, userdata, topic, pid):
    # This method is called when the client unsubscribes from a topic.
    print('Unsubscribed from {0} with PID {1}'.format(topic, pid))

def disconnected(client, userdata, rc):
    # Disconnected function will be called when the client disconnects.
    print('Disconnected from AWS IoT!')
    rect_status.fill = GREEN_DIM

def published(client, userdata, topic, pid):
    # This method is called when the client publishes data to a topic.
    print('Published to {0} with PID {1}'.format(topic, pid))
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
